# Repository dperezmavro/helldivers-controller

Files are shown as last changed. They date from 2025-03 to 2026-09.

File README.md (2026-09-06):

# About
This is a board I made to learn KiCAD and also because I wanted for a while to delve deeper into Arduinos and electronics. 

# Purpose
This is a very basic board that is effectively a macro-pad. It is based around an Arduino Pro Micro and uses 4 toggle switches and 4 push-buttons to provide 4 dual-mode macro-programmable buttons (i.e. each button has an A/B mode). The intention is to use this to call stratagems faster.

Given than you can re-program the ProMicro, this can be changed to your liking.

# Current design
I made the design choice to have the Pro Micro attach to the board using pin headers. This is because I had an arduino die on me whilst prototyping on a perfboard, and I had to restart the whole thing. The pin-header design allows you to swap out the board very easily.

## Schematic
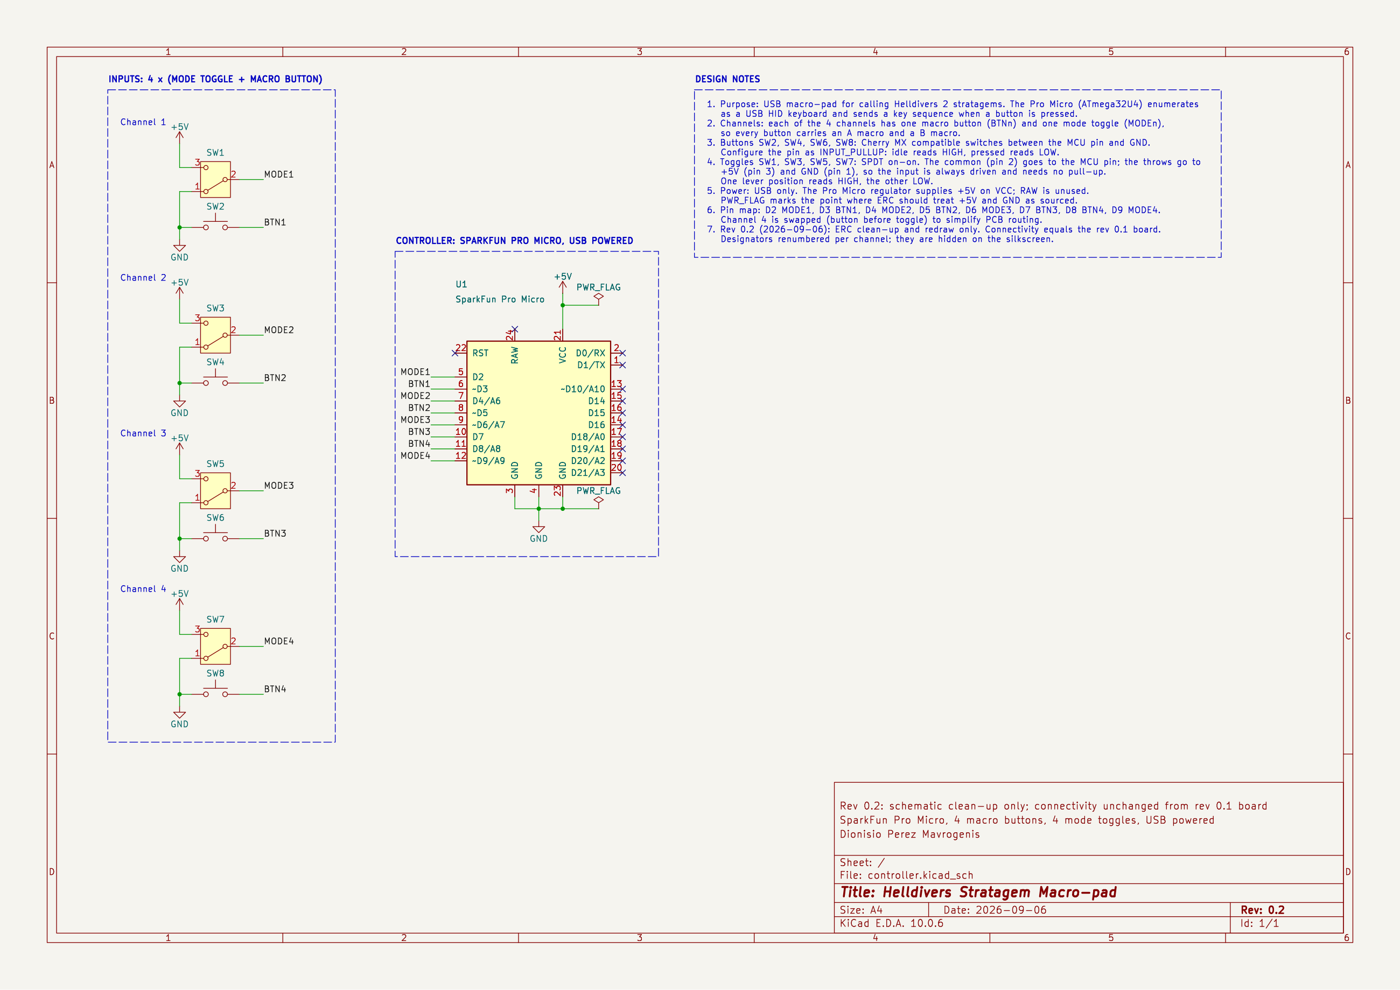
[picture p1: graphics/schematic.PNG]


Each channel has one mode toggle (SW1, SW3, SW5, SW7) and one macro button (SW2, SW4, SW6, SW8). The nets are labelled `MODEn` and `BTNn`; the design notes on the sheet explain the wiring and the pin map. The Pro Micro symbol and the custom footprints (Pro Micro, AEDIKO SPDT toggle, logo) are project-local libraries in `controller/lib`, registered in `controller/sym-lib-table` and `controller/fp-lib-table`, so the project opens without any extra library setup.

## 3d render
This is what the current board render looks like when 3D

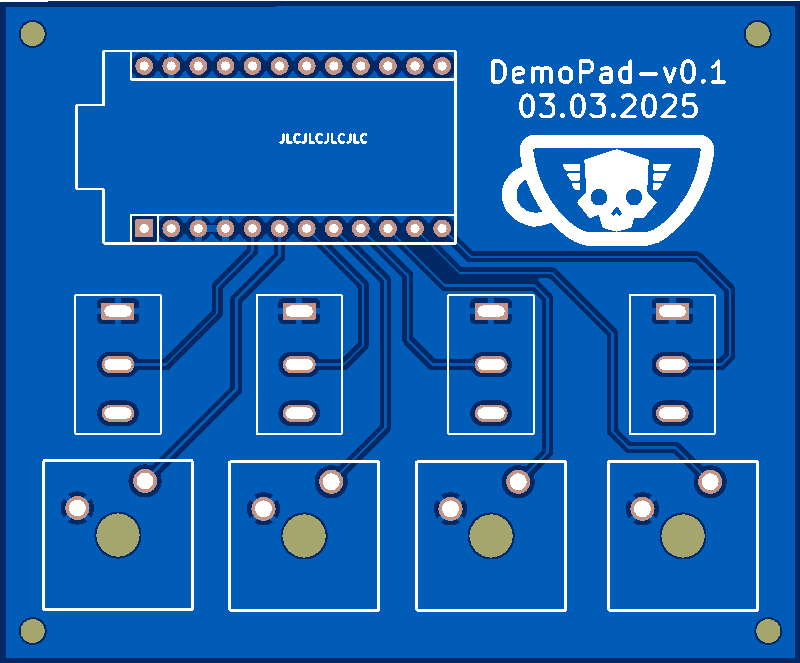
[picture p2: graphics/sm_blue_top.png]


## Assembled
And this is what it looks like after assembled IRL.

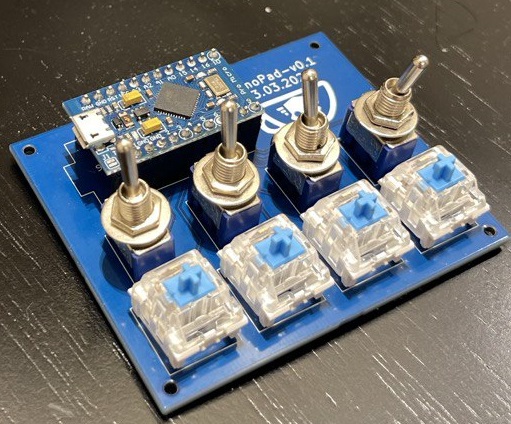
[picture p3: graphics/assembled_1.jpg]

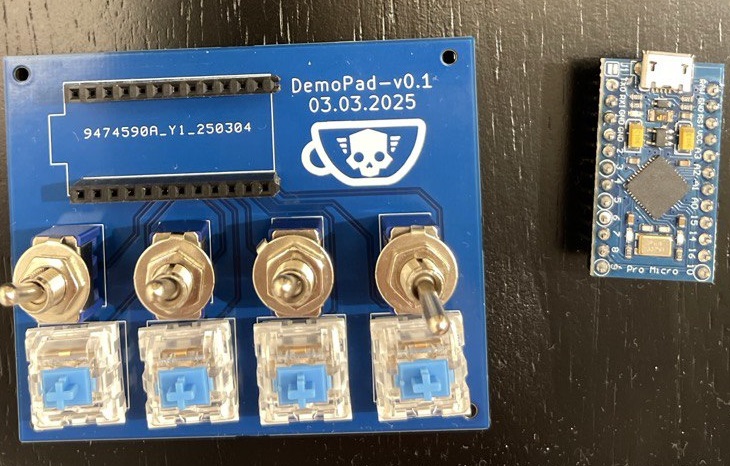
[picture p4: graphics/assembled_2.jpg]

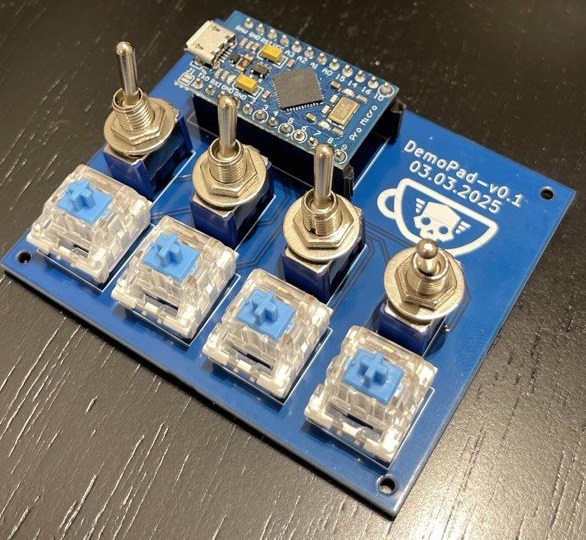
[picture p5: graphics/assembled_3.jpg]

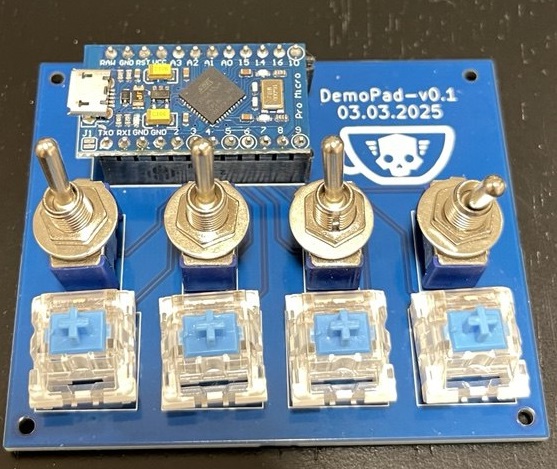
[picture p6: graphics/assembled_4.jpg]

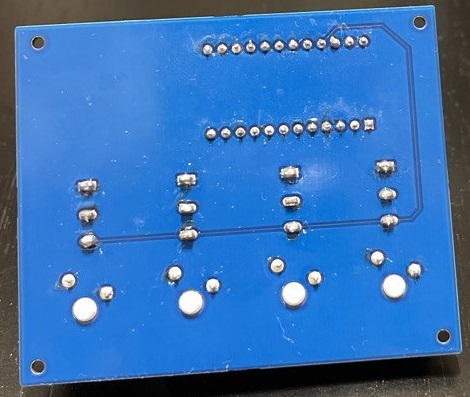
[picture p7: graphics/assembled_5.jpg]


# Future work
Since this is the first PCB that I have designed and fabricated, I have found some bugs in the physical layout of the board. 

## The spacing of they keyboard buttons is too tight to allow for keycaps. 

Keycaps are a 1u width (roughly 17mm) and the current spacing is too tight as I only meassured the keyboard button and did not account for the width of the keycap that would sit on top whilst designing. This means that most keycaps are rubbing both on the keycaps next to them, as well as they toggle switches above them.

## The pinout for the 4th button and switch is reversed. 

This is not so much a bug, as much as a very likely gotcha (and it did get me!). Due to board layout and via routing, I found it easier to switch the pin order for the 4th button and toggle switch combination. The board still works as intended, but this is something to keep in mind when programming. In the schematic this shows as `BTN4` on D8 and `MODE4` on D9, whereas the other channels have the toggle on the lower pin number. 

The 3rd and 4th button vias are also very close to each other, and this might make manufacturing hard/impossible for some providers. 

## Board shape and standoff screws

The current screws are M2, I would change them to M3. I would also round the corners of the board.

## Make this wireless
I would need to work out how to make this a bluetooth-enabled keyboard, and also figure out the power situation.

## Make this wearable

It would be cool to make this wearable, like the pad in the game! This would make most sence if the board is wireless. 

# Lisence

Feel free to replicate this project for your own personal use. No commercial use is allowed (i.e. uses including, but not limited to, commercial manufacturing, resale, reuse, incorporation or integration of parts or the whole of this project).

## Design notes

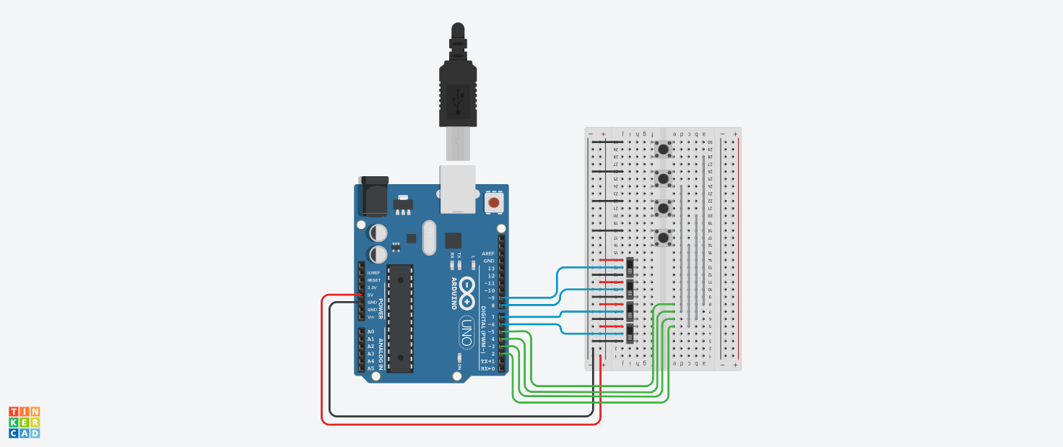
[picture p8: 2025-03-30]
graphics/Helldivers controller.png

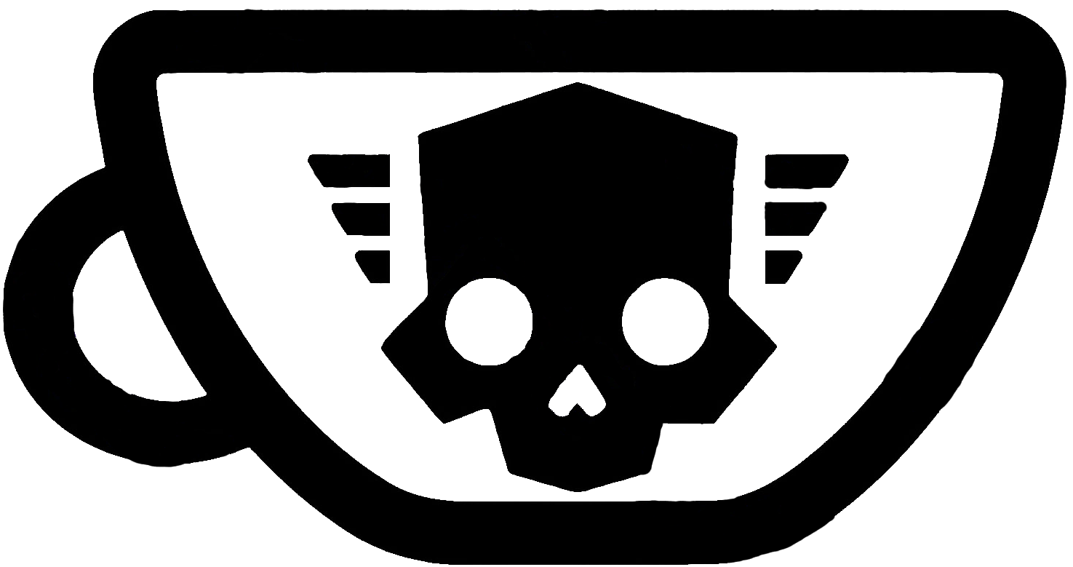
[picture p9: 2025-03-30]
graphics/libertea.png

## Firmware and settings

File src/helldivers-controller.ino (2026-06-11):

#include <Arduino.h>
#include <Keyboard.h>
#include <Mouse.h>
#include <ezButton.h>

#include "debug.h"
#include "stratagem-assignments.h"
#include "time-constants.h"

ezButton slot1(PIN_SLOT_1_BTN, INPUT_PULLUP);
ezButton slot2(PIN_SLOT_2_BTN, INPUT_PULLUP);
ezButton slot3(PIN_SLOT_3_BTN, INPUT_PULLUP);
ezButton slot4(PIN_SLOT_4_BTN, INPUT_PULLUP);

void callStratagem(const char* primary, const char* secondary, int modePin);

void setup() {
  Serial.begin(9600);

  lastSwitchDetectedMillis = millis();

  pinMode(PIN_SLOT_1_TOGGLE, INPUT);
  pinMode(PIN_SLOT_2_TOGGLE, INPUT);
  pinMode(PIN_SLOT_3_TOGGLE, INPUT);
  pinMode(PIN_SLOT_4_TOGGLE, INPUT);

  slot1.setDebounceTime(DEBOUNCE_TIME_MS);
  slot2.setDebounceTime(DEBOUNCE_TIME_MS);
  slot3.setDebounceTime(DEBOUNCE_TIME_MS);
  slot4.setDebounceTime(DEBOUNCE_TIME_MS);

  Keyboard.begin();
  Mouse.begin();

  pinMode(LED_BUILTIN, OUTPUT);
}

void loop() {
  slot1.loop();
  slot2.loop();
  slot3.loop();
  slot4.loop();

  if (slot1.isPressed()) {
    callStratagem(REINFORCE_CODE, STALWART_CODE, PIN_SLOT_1_TOGGLE);
  } else if (slot2.isPressed()) {
    callStratagem(RESUPPLY_CODE, GUARD_DOG_ROVER_CODE, PIN_SLOT_2_TOGGLE);
  } else if (slot3.isPressed()) {
    callStratagem(SENTRY_AUTOCANNON_CODE, MACHINE_GUN_CODE, PIN_SLOT_3_TOGGLE);
  } else if (slot4.isPressed()) {
    callStratagem(EAGLE_NAPALM_AIRSTRIKE_CODE, FIVE_HUNDRED_KG_AIRSTRIKE_CODE, PIN_SLOT_4_TOGGLE);
  }
}

void callStratagem(const char* primary, const char* secondary, int modePin) {
  if (millis() - lastSwitchDetectedMillis < MULTI_TRIGGER_PREVENTION_MS) {
    SERIAL_DEBUG("spotted multiple bounces");
    return;
  }

  lastSwitchDetectedMillis = millis();

  digitalWrite(LED_BUILTIN, HIGH);
  delay(LED_FEEDBACK_MS);
  digitalWrite(LED_BUILTIN, LOW);

  const bool  isPrimary = (digitalRead(modePin) == HIGH);
  const char* stratagem = isPrimary ? primary : secondary;

  SERIAL_DEBUG(isPrimary);
  SERIAL_DEBUG(" ");
  SERIAL_DEBUG(stratagem);
#ifdef DEBUG
  return;
#endif

  Keyboard.press(KEY_LEFT_CTRL);
  delay(WAIT_BETWEEN_KEY_PRESS_MS);

  const size_t len = strlen(stratagem);
  for (size_t i = 0; i < len; ++i) {
    Keyboard.press(static_cast<uint8_t>(stratagem[i]));
    delay(WAIT_BETWEEN_KEY_PRESS_MS);
    Keyboard.release(static_cast<uint8_t>(stratagem[i]));
    delay(WAIT_BETWEEN_KEY_PRESS_MS);
  }

  Mouse.press();
  delay(WAIT_BETWEEN_KEY_PRESS_MS);
  Mouse.release();

  Keyboard.releaseAll();
}

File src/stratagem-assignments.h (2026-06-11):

#ifndef _STRATAGEM_ASSIGNMENTS

#define _STRATAGEM_ASSIGNMENTS

// Pin assignments
constexpr int PIN_SLOT_1_BTN    = 3;
constexpr int PIN_SLOT_1_TOGGLE = 2;
constexpr int PIN_SLOT_2_BTN    = 5;
constexpr int PIN_SLOT_2_TOGGLE = 4;
constexpr int PIN_SLOT_3_BTN    = 7;
constexpr int PIN_SLOT_3_TOGGLE = 6;
constexpr int PIN_SLOT_4_BTN    = 8;
constexpr int PIN_SLOT_4_TOGGLE = 9;

// Slot 1
constexpr char REINFORCE_CODE[] = "wsdaw";
constexpr char STALWART_CODE[]  = "saswwa";

// Slot 2
constexpr char RESUPPLY_CODE[]        = "sswd";
constexpr char GUARD_DOG_ROVER_CODE[] = "swawds";

// Slot 3
constexpr char SENTRY_AUTOCANNON_CODE[] = "swdwaw";
constexpr char MACHINE_GUN_CODE[]       = "saswd";

// Slot 4
constexpr char EAGLE_NAPALM_AIRSTRIKE_CODE[]    = "ddsadw";
constexpr char FIVE_HUNDRED_KG_AIRSTRIKE_CODE[] = "wdsss";

#endif

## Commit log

2026-06-11 reverted to maintain compatibility with arduino ide
    [helldivers-controller.ino]
2026-06-11 reverted c++17 to c++11 to keep it inline with arduino ide
2026-06-11 added sparkfun boards and fixed board model
2026-09-06 added latest kicad
    [controller.kicad_pcb, controller.kicad_sch]
2026-09-06 Fix ERC errors, redraw schematic, add project-local KiCad libraries
    Schematic (rev 0.2, KiCad 9 file format):
    - Add PWR_FLAG on +5V and GND at the Pro Micro, which resolves the two
    "Input Power pin not driven by any Output Power pins" ERC errors.
    - Redraw the SparkFun Pro Micro symbol with power pins on top, ground pins
    at the bottom and the eight used inputs on the left.
    - Replace the fan-out wires with net labels MODE1..4 and BTN1..4, group
    each toggle/button pair as a channel, add design notes, an A4 sheet and
    a filled-in title block.
    - Renumber designators per channel (toggles SW1/3/5/7, buttons SW2/4/6/8).
    References are hidden on the silkscreen, so the fabricated board is not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
    [controller.kicad_pcb, controller.kicad_sch]
